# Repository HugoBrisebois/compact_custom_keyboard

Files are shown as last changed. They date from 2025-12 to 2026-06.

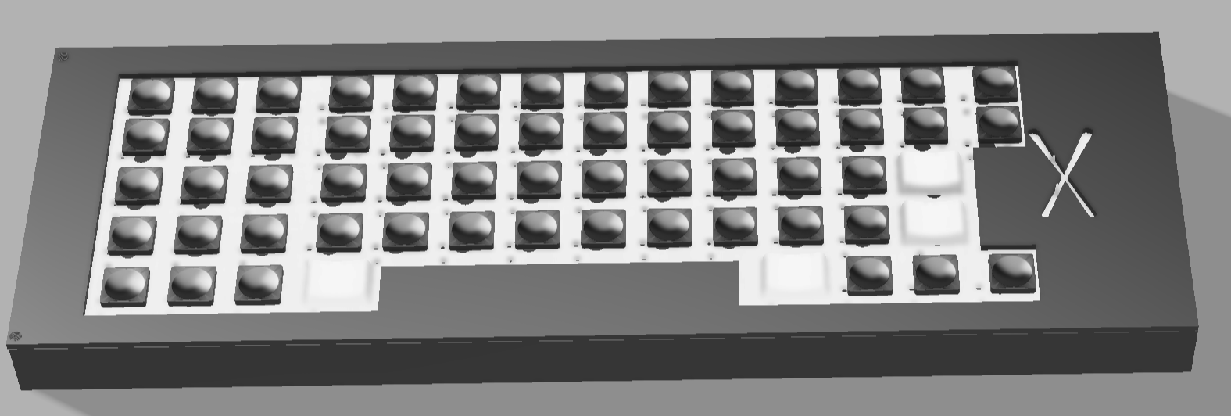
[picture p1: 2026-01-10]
images/render.png

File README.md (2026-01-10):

## Compact Custom Keyboard

This is a compact Keyboard the is powered by a raspberry pi pico and is a hotswapable kailth choc mini keyswitches, the keyboard also has LEDs that can be used for a aestetic lighting and as light to see what you are typing.
The Keyboard is also a 60% keyboard meaning that it is quite small while not having too many layers like a 40% one.

# Features
- powered by a raspberry pi pico
- RGB LEDs
- kailth choc mini keyswitches
- 3d Printed keyswitches

# Reason for build this project
i wanted a keyboard that is completely custom to me and is also something that i can use in a cyberdeck project that i want to build later on. this keyboard is also perfect for everyday use and i am looking forward to using this keyboard too.
case
PCB
3D-render-PCB
Schematic


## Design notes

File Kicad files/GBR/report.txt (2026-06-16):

Plotted to 'C:\Users\iCan Student\OneDrive\Bureau\projects\kicad\compact_custom_keyboard\GBR\keyboardepi pico-F_Cu.gbr'.
Plotted to 'C:\Users\iCan Student\OneDrive\Bureau\projects\kicad\compact_custom_keyboard\GBR\keyboardepi pico-B_Cu.gbr'.
Plotted to 'C:\Users\iCan Student\OneDrive\Bureau\projects\kicad\compact_custom_keyboard\GBR\keyboardepi pico-F_Paste.gbr'.
Plotted to 'C:\Users\iCan Student\OneDrive\Bureau\projects\kicad\compact_custom_keyboard\GBR\keyboardepi pico-B_Paste.gbr'.
Plotted to 'C:\Users\iCan Student\OneDrive\Bureau\projects\kicad\compact_custom_keyboard\GBR\keyboardepi pico-F_Silkscreen.gbr'.
Plotted to 'C:\Users\iCan Student\OneDrive\Bureau\projects\kicad\compact_custom_keyboard\GBR\keyboardepi pico-B_Silkscreen.gbr'.
Plotted to 'C:\Users\iCan Student\OneDrive\Bureau\projects\kicad\compact_custom_keyboard\GBR\keyboardepi pico-F_Mask.gbr'.
Plotted to 'C:\Users\iCan Student\OneDrive\Bureau\projects\kicad\compact_custom_keyboard\GBR\keyboardepi pico-B_Mask.gbr'.
Plotted to 'C:\Users\iCan Student\OneDrive\Bureau\projects\kicad\compact_custom_keyboard\GBR\keyboardepi pico-Edge_Cuts.gbr'.
Created Gerber job file 'C:\Users\iCan Student\OneDrive\Bureau\projects\kicad\compact_custom_keyboard\GBR\keyboardepi pico-job.gbrjob'.
Info: Done.
Info: Done.

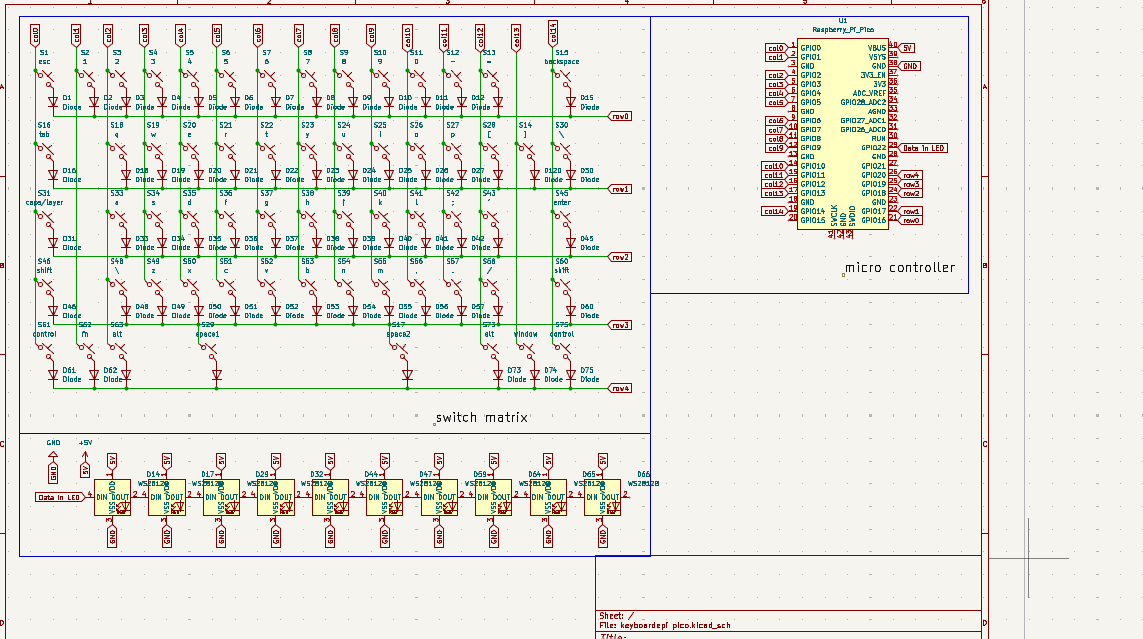
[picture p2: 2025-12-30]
images/Schematic.png

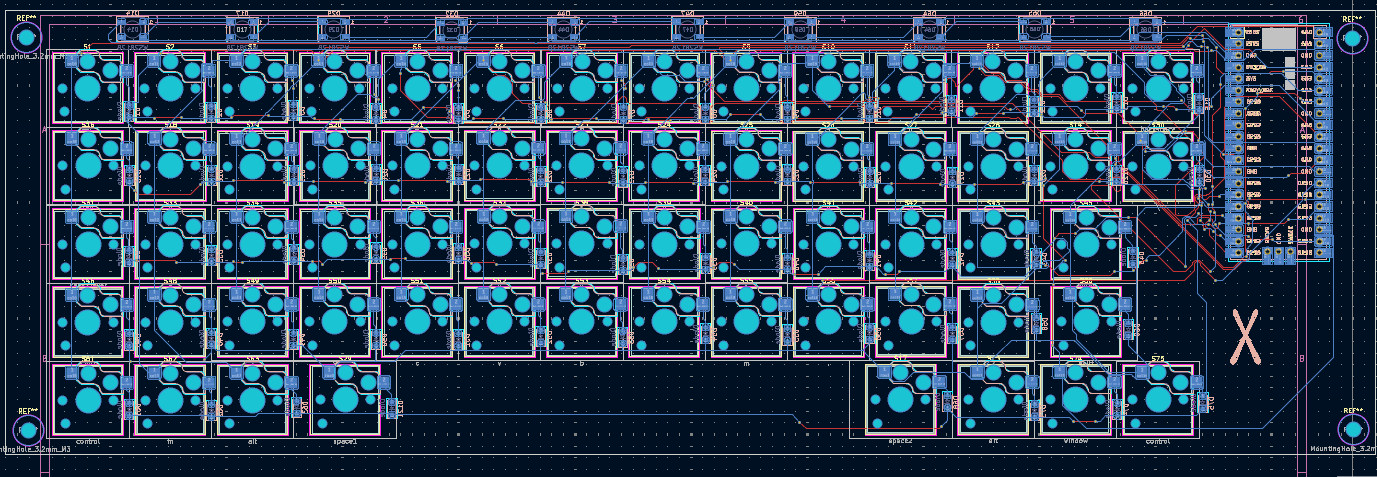
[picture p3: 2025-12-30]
images/PCB.png

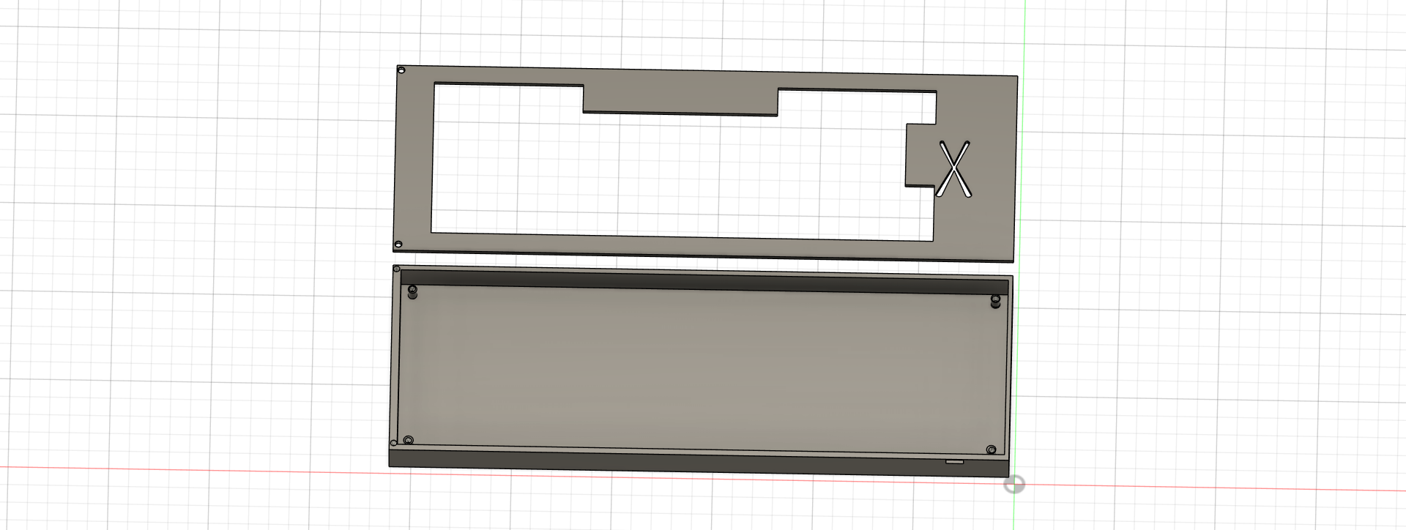
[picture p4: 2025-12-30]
images/case.png

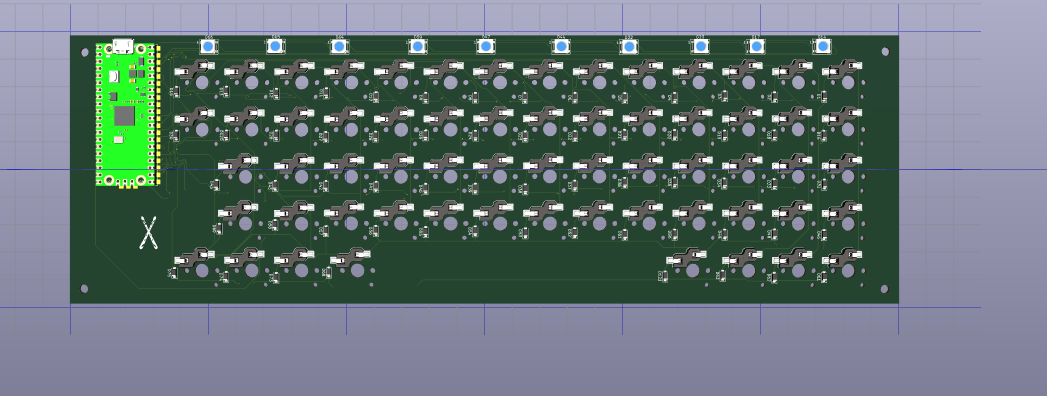
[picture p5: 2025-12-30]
images/3D-render-PCB.png

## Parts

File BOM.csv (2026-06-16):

Reference | Qty | Value | DNP | Exclude from BOM | Exclude from Board | Footprint | Datasheet | Price | Website
D1,D2,D3,D4,D5,D6,D7,D8,D9,D10,D11,D12,D13,D15,D16,D18,D19,D20,D21,D22,D23,D24,D25,D26,D27,D28,D30,D31,D33,D34,D35,D36,D37,D38,D39,D40,D41,D42,D43,D45,D46,D48,D49,D50,D51,D52,D53,D54,D55,D56,D57,D58,D60,D61,D62,D63,D68,D73,D74,D75,D120,D121 | 62 | Diode |  |  |  | Diode_SMD:D_SOD-123F |  | $1.41 | https://www.aliexpress.com/item/1005007536859190.html?curPageLogUid=P8NopE6CzZ6E
D14,D17,D29,D32,D44,D47,D59,D64,D65,D66 | 10 | WS2812B |  |  |  | LED_SMD:LED_WS2812B_PLCC4_5.0x5.0mm_P3.2mm | https://cdn-shop.adafruit.com/datasheets/WS2812B.pdf | $1.74 | https://www.aliexpress.com/item/1005001376489095.html?curPageLogUid=NBeugOt4vb7Q
S1 | 1 | esc |  |  |  | PCM_Switch_Keyboard_Hotswap_Kailh:SW_Hotswap_Kailh_Choc_V1V2_1.00u | ~ |  | 0.35 | unit price
S2 | 1 | 1 |  |  |  | PCM_Switch_Keyboard_Hotswap_Kailh:SW_Hotswap_Kailh_Choc_V1V2_1.00u | ~ |  | 0.35 | unit price
S3 | 1 | 2 |  |  |  | PCM_Switch_Keyboard_Hotswap_Kailh:SW_Hotswap_Kailh_Choc_V1V2_1.00u | ~ |  | 0.35 | unit price
S4 | 1 | 3 |  |  |  | PCM_Switch_Keyboard_Hotswap_Kailh:SW_Hotswap_Kailh_Choc_V1V2_1.00u | ~ |  | 0.35 | unit price
S5 | 1 | 4 |  |  |  | PCM_Switch_Keyboard_Hotswap_Kailh:SW_Hotswap_Kailh_Choc_V1V2_1.00u | ~ |  | 0.35 | unit price
S6 | 1 | 5 |  |  |  | PCM_Switch_Keyboard_Hotswap_Kailh:SW_Hotswap_Kailh_Choc_V1V2_1.00u | ~ |  | 0.35 | unit price
S7 | 1 | 6 |  |  |  | PCM_Switch_Keyboard_Hotswap_Kailh:SW_Hotswap_Kailh_Choc_V1V2_1.00u | ~ |  | 0.35 | unit price
S8 | 1 | 7 |  |  |  | PCM_Switch_Keyboard_Hotswap_Kailh:SW_Hotswap_Kailh_Choc_V1V2_1.00u | ~ |  | 0.35 | unit price
S9 | 1 | 8 |  |  |  | PCM_Switch_Keyboard_Hotswap_Kailh:SW_Hotswap_Kailh_Choc_V1V2_1.00u | ~ |  | 0.35 | unit price
S10 | 1 | 9 |  |  |  | PCM_Switch_Keyboard_Hotswap_Kailh:SW_Hotswap_Kailh_Choc_V1V2_1.00u | ~ |  | 0.35 | unit price
S11 | 1 | 0 |  |  |  | PCM_Switch_Keyboard_Hotswap_Kailh:SW_Hotswap_Kailh_Choc_V1V2_1.00u | ~ |  | 0.35 | unit price
S12 | 1 | - |  |  |  | PCM_Switch_Keyboard_Hotswap_Kailh:SW_Hotswap_Kailh_Choc_V1V2_1.00u | ~ |  | 0.35 | unit price
S13 | 1 | = |  |  |  | PCM_Switch_Keyboard_Hotswap_Kailh:SW_Hotswap_Kailh_Choc_V1V2_1.00u | ~ |  | 0.35 | unit price
S14 | 1 | ] |  |  |  | PCM_Switch_Keyboard_Hotswap_Kailh:SW_Hotswap_Kailh_Choc_V1V2_1.00u | ~ |  | 0.35 | unit price
S15 | 1 | backspace |  |  |  | PCM_Switch_Keyboard_Hotswap_Kailh:SW_Hotswap_Kailh_Choc_V1V2_1.00u | ~ |  | 0.35 | unit price
S16 | 1 | tab |  |  |  | PCM_Switch_Keyboard_Hotswap_Kailh:SW_Hotswap_Kailh_Choc_V1V2_1.00u | ~ |  | 0.35 | unit price
S17 | 1 | space2 |  |  |  | PCM_Switch_Keyboard_Hotswap_Kailh:SW_Hotswap_Kailh_Choc_V1V2_1.25u | ~ |  | 0.35 | unit price
S18 | 1 | q |  |  |  | PCM_Switch_Keyboard_Hotswap_Kailh:SW_Hotswap_Kailh_Choc_V1V2_1.00u | ~ |  | 0.35 | unit price
S19 | 1 | w |  |  |  | PCM_Switch_Keyboard_Hotswap_Kailh:SW_Hotswap_Kailh_Choc_V1V2_1.00u | ~ |  | 0.35 | unit price
S20 | 1 | e |  |  |  | PCM_Switch_Keyboard_Hotswap_Kailh:SW_Hotswap_Kailh_Choc_V1V2_1.00u | ~ |  | 0.35 | unit price
S21 | 1 | r |  |  |  | PCM_Switch_Keyboard_Hotswap_Kailh:SW_Hotswap_Kailh_Choc_V1V2_1.00u | ~ |  | 0.35 | unit price
S22 | 1 | t |  |  |  | PCM_Switch_Keyboard_Hotswap_Kailh:SW_Hotswap_Kailh_Choc_V1V2_1.00u | ~ |  | 0.35 | unit price
S23 | 1 | y |  |  |  | PCM_Switch_Keyboard_Hotswap_Kailh:SW_Hotswap_Kailh_Choc_V1V2_1.00u | ~ |  | 0.35 | unit price
S24 | 1 | u |  |  |  | PCM_Switch_Keyboard_Hotswap_Kailh:SW_Hotswap_Kailh_Choc_V1V2_1.00u | ~ |  | 0.35 | unit price
S25 | 1 | i |  |  |  | PCM_Switch_Keyboard_Hotswap_Kailh:SW_Hotswap_Kailh_Choc_V1V2_1.00u | ~ |  | 0.35 | unit price
S26 | 1 | o |  |  |  | PCM_Switch_Keyboard_Hotswap_Kailh:SW_Hotswap_Kailh_Choc_V1V2_1.00u | ~ |  | 0.35 | unit price
S27 | 1 | p |  |  |  | PCM_Switch_Keyboard_Hotswap_Kailh:SW_Hotswap_Kailh_Choc_V1V2_1.00u | ~ |  | 0.35 | unit price
S28 | 1 | [ |  |  |  | PCM_Switch_Keyboard_Hotswap_Kailh:SW_Hotswap_Kailh_Choc_V1V2_1.00u | ~ |  | 0.35 | unit price
S29 | 1 | space1 |  |  |  | PCM_Switch_Keyboard_Hotswap_Kailh:SW_Hotswap_Kailh_Choc_V1V2_1.25u | ~ |  | 0.35 | unit price
S30,S48 | 2 | \ |  |  |  | PCM_Switch_Keyboard_Hotswap_Kailh:SW_Hotswap_Kailh_Choc_V1V2_1.00u | ~ |  | 0.35 | unit price
S31 | 1 | caps/layer |  |  |  | PCM_Switch_Keyboard_Hotswap_Kailh:SW_Hotswap_Kailh_Choc_V1V2_1.00u | ~ |  | 0.35 | unit price
S33 | 1 | a |  |  |  | PCM_Switch_Keyboard_Hotswap_Kailh:SW_Hotswap_Kailh_Choc_V1V2_1.00u | ~ |  | 0.35 | unit price
S34 | 1 | s |  |  |  | PCM_Switch_Keyboard_Hotswap_Kailh:SW_Hotswap_Kailh_Choc_V1V2_1.00u | ~ |  | 0.35 | unit price
S35 | 1 | d |  |  |  | PCM_Switch_Keyboard_Hotswap_Kailh:SW_Hotswap_Kailh_Choc_V1V2_1.00u | ~ |  | 0.35 | unit price
S36 | 1 | f |  |  |  | PCM_Switch_Keyboard_Hotswap_Kailh:SW_Hotswap_Kailh_Choc_V1V2_1.00u | ~ |  | 0.35 | unit price
S37 | 1 | g |  |  |  | PCM_Switch_Keyboard_Hotswap_Kailh:SW_Hotswap_Kailh_Choc_V1V2_1.00u | ~ |  | 0.35 | unit price
S38 | 1 | h |  |  |  | PCM_Switch_Keyboard_Hotswap_Kailh:SW_Hotswap_Kailh_Choc_V1V2_1.00u | ~ |  | 0.35 | unit price
S39 | 1 | j |  |  |  | PCM_Switch_Keyboard_Hotswap_Kailh:SW_Hotswap_Kailh_Choc_V1V2_1.00u | ~ |  | 0.35 | unit price
S40 | 1 | k |  |  |  | PCM_Switch_Keyboard_Hotswap_Kailh:SW_Hotswap_Kailh_Choc_V1V2_1.00u | ~ |  | 0.35 | unit price
S41 | 1 | l |  |  |  | PCM_Switch_Keyboard_Hotswap_Kailh:SW_Hotswap_Kailh_Choc_V1V2_1.00u | ~ |  | 0.35 | unit price
S42 | 1 | ; |  |  |  | PCM_Switch_Keyboard_Hotswap_Kailh:SW_Hotswap_Kailh_Choc_V1V2_1.00u | ~ |  | 0.35 | unit price
S43 | 1 | ' |  |  |  | PCM_Switch_Keyboard_Hotswap_Kailh:SW_Hotswap_Kailh_Choc_V1V2_1.00u | ~ |  | 0.35 | unit price
S45 | 1 | enter |  |  |  | PCM_Switch_Keyboard_Hotswap_Kailh:SW_Hotswap_Kailh_Choc_V1V2_1.25u | ~ |  | 0.35 | unit price
S46 | 1 | shift |  |  |  | PCM_Switch_Keyboard_Hotswap_Kailh:SW_Hotswap_Kailh_Choc_V1V2_1.00u | ~ |  | 0.35 | unit price
S49 | 1 | z |  |  |  | PCM_Switch_Keyboard_Hotswap_Kailh:SW_Hotswap_Kailh_Choc_V1V2_1.00u | ~ |  | 0.35 | unit price
S50 | 1 | x |  |  |  | PCM_Switch_Keyboard_Hotswap_Kailh:SW_Hotswap_Kailh_Choc_V1V2_1.00u | ~ |  | 0.35 | unit price
S51 | 1 | c |  |  |  | PCM_Switch_Keyboard_Hotswap_Kailh:SW_Hotswap_Kailh_Choc_V1V2_1.00u | ~ |  | 0.35 | unit price
S52 | 1 | v |  |  |  | PCM_Switch_Keyboard_Hotswap_Kailh:SW_Hotswap_Kailh_Choc_V1V2_1.00u | ~ |  | 0.35 | unit price
S53 | 1 | b |  |  |  | PCM_Switch_Keyboard_Hotswap_Kailh:SW_Hotswap_Kailh_Choc_V1V2_1.00u | ~ |  | 0.35 | unit price
S54 | 1 | n |  |  |  | PCM_Switch_Keyboard_Hotswap_Kailh:SW_Hotswap_Kailh_Choc_V1V2_1.00u | ~ |  | 0.35 | unit price
S55 | 1 | m |  |  |  | PCM_Switch_Keyboard_Hotswap_Kailh:SW_Hotswap_Kailh_Choc_V1V2_1.00u | ~ |  | 0.35 | unit price
S56 | 1 | , |  |  |  | PCM_Switch_Keyboard_Hotswap_Kailh:SW_Hotswap_Kailh_Choc_V1V2_1.00u | ~ |  | 0.35 | unit price
S57 | 1 | . |  |  |  | PCM_Switch_Keyboard_Hotswap_Kailh:SW_Hotswap_Kailh_Choc_V1V2_1.00u | ~ |  | 0.35 | unit price
S58 | 1 | / |  |  |  | PCM_Switch_Keyboard_Hotswap_Kailh:SW_Hotswap_Kailh_Choc_V1V2_1.00u | ~ |  | 0.35 | unit price
S60 | 1 | shift |  |  |  | PCM_Switch_Keyboard_Hotswap_Kailh:SW_Hotswap_Kailh_Choc_V1V2_1.25u | ~ |  | 0.35 | unit price
S61,S75 | 2 | control |  |  |  | PCM_Switch_Keyboard_Hotswap_Kailh:SW_Hotswap_Kailh_Choc_V1V2_1.00u | ~ |  | 0.35 | unit price
S62 | 1 | fn |  |  |  | PCM_Switch_Keyboard_Hotswap_Kailh:SW_Hotswap_Kailh_Choc_V1V2_1.00u | ~ |  | 0.35 | unit price
S63,S73 | 2 | alt |  |  |  | PCM_Switch_Keyboard_Hotswap_Kailh:SW_Hotswap_Kailh_Choc_V1V2_1.00u | ~ |  | 0.35 | unit price
S74 | 1 | window |  |  |  | PCM_Switch_Keyboard_Hotswap_Kailh:SW_Hotswap_Kailh_Choc_V1V2_1.00u | ~ |  | 0.35 | unit price
U1 | 1 | Raspberry_Pi_Pico |  |  |  | ScottoKeebs_MCU:Raspberry_Pi_Pico |  | $3.80 | https://www.aliexpress.com/item/1005008379427391.html?mp=1
PCB Total Cost + shipping |  |  |  |  |  |  |  | $30.25 | shipping option | DDP
Total Keyswitches |  |  | 62 |  |  |  |  | $27.52 | https://www.aliexpress.us/item/3256808620484354.html?curPageLogUid=S7K5j9DP5AhE
 |  |  |  |  |  |  |  | (First Purchase discount)
Total Hotswap sockets |  |  | 62 |  |  |  |  | $8.32 | https://www.aliexpress.com/item/1005009312876316.html?curPageLogUid=QmGdVVpTZLfK
 |  |  |  |  | Total Cost |  |  | $73.04

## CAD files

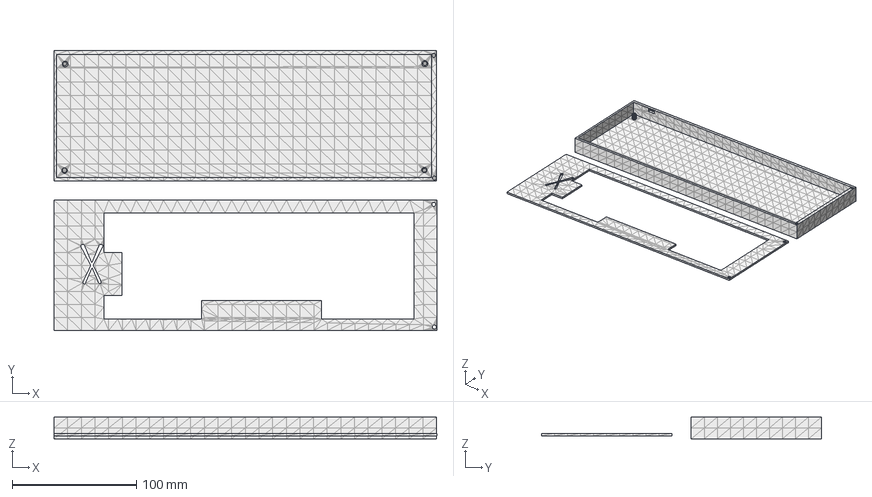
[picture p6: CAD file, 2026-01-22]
3D model case/Case.step
308.3 x 225.3 x 17.5 mm

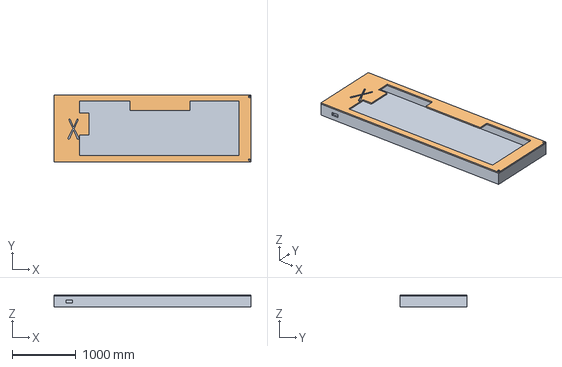
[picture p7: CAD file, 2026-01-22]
3D model case/PCB with Case(keyboard).step
3083.4 x 1050.2 x 195.0 mm

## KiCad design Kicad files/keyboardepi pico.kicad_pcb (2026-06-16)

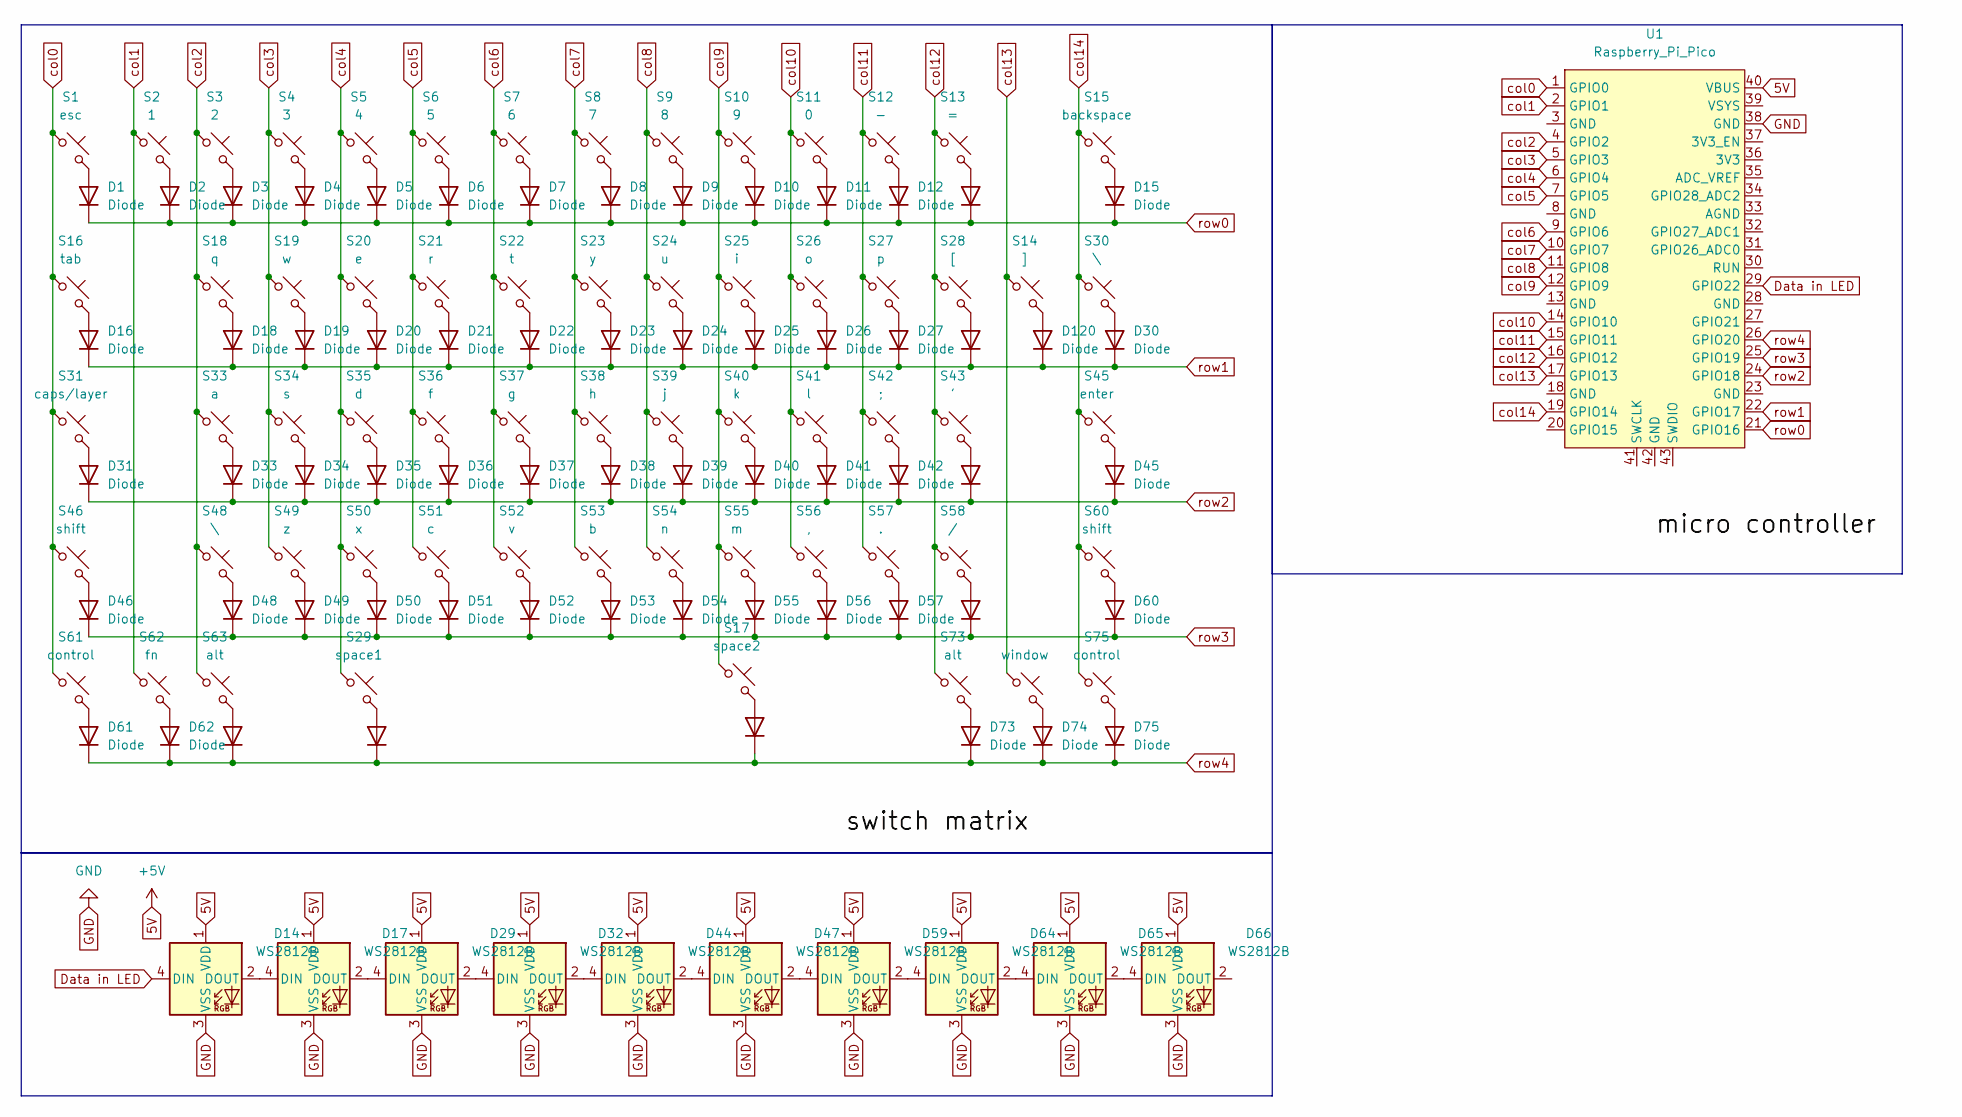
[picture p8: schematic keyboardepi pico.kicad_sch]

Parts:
D1, D2, D3, D4, D5, D6, D7, D8, D9, D10, D11, D12, D13, D15, D16, D18, D19, D20, D21, D22, D23, D24, D25, D26, D27, D28, D30, D31, D33, D34, D35, D36, D37, D38, D39, D40, D41, D42, D43, D45, D46, D48, D49, D50, D51, D52, D53, D54, D55, D56, D57, D58, D60, D61, D62, D63, D68, D73, D74, D75, D120, D121: Diode; Diode_DO-35
D14, D17, D29, D32, D44, D47, D59, D64, D65, D66: WS2812B; LED_WS2812B_PLCC4_5.0x5.0mm_P3.2mm
S1: esc; SW_Hotswap_Kailh_Choc_V1V2_1.00u
S2: 1; SW_Hotswap_Kailh_Choc_V1V2_1.00u
S3: 2; SW_Hotswap_Kailh_Choc_V1V2_1.00u
S4: 3; SW_Hotswap_Kailh_Choc_V1V2_1.00u
S5: 4; SW_Hotswap_Kailh_Choc_V1V2_1.00u
S6: 5; SW_Hotswap_Kailh_Choc_V1V2_1.00u
S7: 6; SW_Hotswap_Kailh_Choc_V1V2_1.00u
S8: 7; SW_Hotswap_Kailh_Choc_V1V2_1.00u
S9: 8; SW_Hotswap_Kailh_Choc_V1V2_1.00u
S10: 9; SW_Hotswap_Kailh_Choc_V1V2_1.00u
S11: 0; SW_Hotswap_Kailh_Choc_V1V2_1.00u
S12: -; SW_Hotswap_Kailh_Choc_V1V2_1.00u
S13: =; SW_Hotswap_Kailh_Choc_V1V2_1.00u
S14: ]; SW_Hotswap_Kailh_Choc_V1V2_1.00u
S15: backspace; SW_Hotswap_Kailh_Choc_V1V2_1.00u
S16: tab; SW_Hotswap_Kailh_Choc_V1V2_1.00u
S17: space2; SW_Hotswap_Kailh_Choc_V1V2_1.25u
S18: q; SW_Hotswap_Kailh_Choc_V1V2_1.00u
S19: w; SW_Hotswap_Kailh_Choc_V1V2_1.00u
S20: e; SW_Hotswap_Kailh_Choc_V1V2_1.00u
S21: r; SW_Hotswap_Kailh_Choc_V1V2_1.00u
S22: t; SW_Hotswap_Kailh_Choc_V1V2_1.00u
S23: y; SW_Hotswap_Kailh_Choc_V1V2_1.00u
S24: u; SW_Hotswap_Kailh_Choc_V1V2_1.00u
S25: i; SW_Hotswap_Kailh_Choc_V1V2_1.00u
S26: o; SW_Hotswap_Kailh_Choc_V1V2_1.00u
S27: p; SW_Hotswap_Kailh_Choc_V1V2_1.00u
S28: [; SW_Hotswap_Kailh_Choc_V1V2_1.00u
S29: space1; SW_Hotswap_Kailh_Choc_V1V2_1.25u
S30, S48: \; SW_Hotswap_Kailh_Choc_V1V2_1.00u
S31: caps/layer; SW_Hotswap_Kailh_Choc_V1V2_1.00u
S33: a; SW_Hotswap_Kailh_Choc_V1V2_1.00u
S34: s; SW_Hotswap_Kailh_Choc_V1V2_1.00u
S35: d; SW_Hotswap_Kailh_Choc_V1V2_1.00u
S36: f; SW_Hotswap_Kailh_Choc_V1V2_1.00u
S37: g; SW_Hotswap_Kailh_Choc_V1V2_1.00u
S38: h; SW_Hotswap_Kailh_Choc_V1V2_1.00u
S39: j; SW_Hotswap_Kailh_Choc_V1V2_1.00u
S40: k; SW_Hotswap_Kailh_Choc_V1V2_1.00u
S41: l; SW_Hotswap_Kailh_Choc_V1V2_1.00u
S42: ;; SW_Hotswap_Kailh_Choc_V1V2_1.00u
S43: '; SW_Hotswap_Kailh_Choc_V1V2_1.00u
S45: enter; SW_Hotswap_Kailh_Choc_V1V2_1.25u
S46: shift; SW_Hotswap_Kailh_Choc_V1V2_1.00u
S49: z; SW_Hotswap_Kailh_Choc_V1V2_1.00u
S50: x; SW_Hotswap_Kailh_Choc_V1V2_1.00u
S51: c; SW_Hotswap_Kailh_Choc_V1V2_1.00u
S52: v; SW_Hotswap_Kailh_Choc_V1V2_1.00u
S53: b; SW_Hotswap_Kailh_Choc_V1V2_1.00u
S54: n; SW_Hotswap_Kailh_Choc_V1V2_1.00u
S55: m; SW_Hotswap_Kailh_Choc_V1V2_1.00u
S56: ,; SW_Hotswap_Kailh_Choc_V1V2_1.00u
S57: .; SW_Hotswap_Kailh_Choc_V1V2_1.00u
S58: /; SW_Hotswap_Kailh_Choc_V1V2_1.00u
S60: shift; SW_Hotswap_Kailh_Choc_V1V2_1.25u
S61, S75: control; SW_Hotswap_Kailh_Choc_V1V2_1.00u
S62: fn; SW_Hotswap_Kailh_Choc_V1V2_1.00u
S63, S73: alt; SW_Hotswap_Kailh_Choc_V1V2_1.00u
S74: window; SW_Hotswap_Kailh_Choc_V1V2_1.00u
U1: Raspberry_Pi_Pico

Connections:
5V: D14.1 (VDD), D17.1 (VDD), D29.1 (VDD), D32.1 (VDD), D44.1 (VDD), D47.1 (VDD), D59.1 (VDD), D64.1 (VDD), D65.1 (VDD), D66.1 (VDD), U1.40 (VBUS)
Data in LED: D14.4 (DIN), U1.29 (GPIO22)
GND: D14.3 (VSS), D17.3 (VSS), D29.3 (VSS), D32.3 (VSS), D44.3 (VSS), D47.3 (VSS), D59.3 (VSS), D64.3 (VSS), D65.3 (VSS), D66.3 (VSS), U1.38 (GND)
unnamed: D1.2 (A), S1.2
unnamed: D2.2 (A), S2.2
unnamed: D3.2 (A), S3.2
unnamed: D4.2 (A), S4.2
unnamed: D5.2 (A), S5.2
unnamed: D6.2 (A), S6.2
unnamed: D7.2 (A), S7.2
unnamed: D8.2 (A), S8.2
unnamed: D9.2 (A), S9.2
unnamed: D10.2 (A), S10.2
unnamed: D11.2 (A), S11.2
unnamed: D12.2 (A), S12.2
unnamed: D13.2 (A), S13.2
unnamed: D14.2 (DOUT), D17.4 (DIN)
unnamed: D15.2 (A), S15.2
unnamed: D16.2 (A), S16.2
unnamed: D17.2 (DOUT), D29.4 (DIN)
unnamed: D18.2 (A), S18.2
unnamed: D19.2 (A), S19.2
unnamed: D20.2 (A), S20.2
unnamed: D21.2 (A), S21.2
unnamed: D22.2 (A), S22.2
unnamed: D23.2 (A), S23.2
unnamed: D24.2 (A), S24.2
unnamed: D25.2 (A), S25.2
unnamed: D26.2 (A), S26.2
unnamed: D27.2 (A), S27.2
unnamed: D28.2 (A), S28.2
unnamed: D29.2 (DOUT), D32.4 (DIN)
unnamed: D30.2 (A), S30.2
unnamed: D31.2 (A), S31.2
unnamed: D32.2 (DOUT), D44.4 (DIN)
unnamed: D33.2 (A), S33.2
unnamed: D34.2 (A), S34.2
unnamed: D35.2 (A), S35.2
unnamed: D36.2 (A), S36.2
unnamed: D37.2 (A), S37.2
unnamed: D38.2 (A), S38.2
unnamed: D39.2 (A), S39.2
unnamed: D40.2 (A), S40.2
unnamed: D41.2 (A), S41.2
unnamed: D42.2 (A), S42.2
unnamed: D43.2 (A), S43.2
unnamed: D44.2 (DOUT), D47.4 (DIN)
unnamed: D45.2 (A), S45.2
unnamed: D46.2 (A), S46.2
unnamed: D47.2 (DOUT), D59.4 (DIN)
unnamed: D48.2 (A), S48.2
unnamed: D49.2 (A), S49.2
unnamed: D50.2 (A), S50.2
unnamed: D51.2 (A), S51.2
unnamed: D52.2 (A), S52.2
unnamed: D53.2 (A), S53.2
unnamed: D54.2 (A), S54.2
unnamed: D55.2 (A), S55.2
unnamed: D56.2 (A), S56.2
unnamed: D57.2 (A), S57.2
unnamed: D58.2 (A), S58.2
unnamed: D59.2 (DOUT), D64.4 (DIN)
unnamed: D60.2 (A), S60.2
unnamed: D61.2 (A), S61.2
unnamed: D62.2 (A), S62.2
unnamed: D63.2 (A), S63.2
unnamed: D64.2 (DOUT), D65.4 (DIN)
unnamed: D65.2 (DOUT), D66.4 (DIN)
unnamed: D68.2 (A), S17.2
unnamed: D73.2 (A), S73.2
unnamed: D74.2 (A), S74.2
unnamed: D75.2 (A), S75.2
unnamed: D120.2 (A), S14.2
unnamed: D121.2 (A), S29.2
col0: S1.1, S16.1, S31.1, S46.1, S61.1, U1.1 (GPIO0)
col1: S2.1, S62.1, U1.2 (GPIO1)
col2: S3.1, S18.1, S33.1, S48.1, S63.1, U1.4 (GPIO2)
col3: S4.1, S19.1, S34.1, S49.1, U1.5 (GPIO3)
col4: S5.1, S20.1, S29.1, S35.1, S50.1, U1.6 (GPIO4)
col5: S6.1, S21.1, S36.1, S51.1, U1.7 (GPIO5)
col6: S7.1, S22.1, S37.1, S52.1, U1.9 (GPIO6)
col7: S8.1, S23.1, S38.1, S53.1, U1.10 (GPIO7)
col8: S9.1, S24.1, S39.1, S54.1, U1.11 (GPIO8)
col9: S10.1, S17.1, S25.1, S40.1, S55.1, U1.12 (GPIO9)
col10: S11.1, S26.1, S41.1, S56.1, U1.14 (GPIO10)
col11: S12.1, S27.1, S42.1, S57.1, U1.15 (GPIO11)
col12: S13.1, S28.1, S43.1, S58.1, S73.1, U1.16 (GPIO12)
col13: S14.1, S74.1, U1.17 (GPIO13)
col14: S15.1, S30.1, S45.1, S60.1, S75.1, U1.19 (GPIO14)
row0: D1.1 (K), D2.1 (K), D3.1 (K), D4.1 (K), D5.1 (K), D6.1 (K), D7.1 (K), D8.1 (K), D9.1 (K), D10.1 (K), D11.1 (K), D12.1 (K), D13.1 (K), D15.1 (K), U1.21 (GPIO16)
row1: D16.1 (K), D18.1 (K), D19.1 (K), D20.1 (K), D21.1 (K), D22.1 (K), D23.1 (K), D24.1 (K), D25.1 (K), D26.1 (K), D27.1 (K), D28.1 (K), D30.1 (K), D120.1 (K), U1.22 (GPIO17)
row2: D31.1 (K), D33.1 (K), D34.1 (K), D35.1 (K), D36.1 (K), D37.1 (K), D38.1 (K), D39.1 (K), D40.1 (K), D41.1 (K), D42.1 (K), D43.1 (K), D45.1 (K), U1.24 (GPIO18)
row3: D46.1 (K), D48.1 (K), D49.1 (K), D50.1 (K), D51.1 (K), D52.1 (K), D53.1 (K), D54.1 (K), D55.1 (K), D56.1 (K), D57.1 (K), D58.1 (K), D60.1 (K), U1.25 (GPIO19)
row4: D61.1 (K), D62.1 (K), D63.1 (K), D68.1 (K), D73.1 (K), D74.1 (K), D75.1 (K), D121.1 (K), U1.26 (GPIO20)

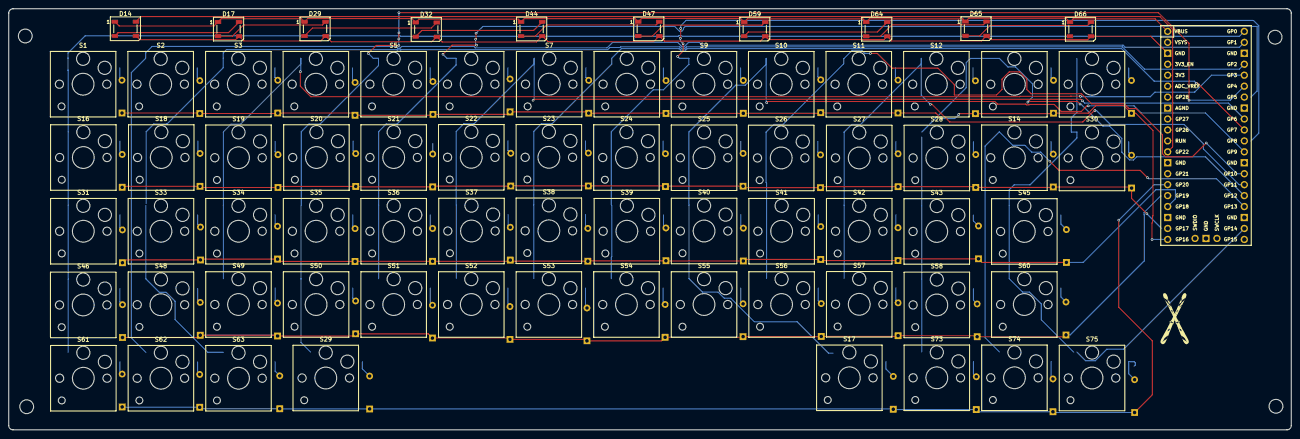
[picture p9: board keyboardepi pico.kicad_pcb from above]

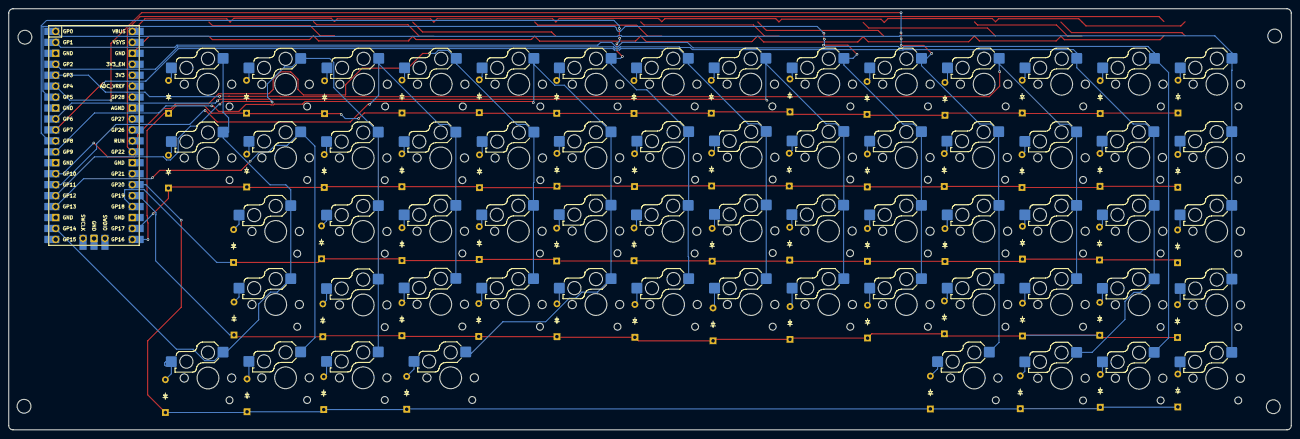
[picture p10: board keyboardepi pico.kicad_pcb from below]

Board: 2 copper layers, 297.5 x 97.7 mm, 135 parts (63 on the bottom side), 94 nets.

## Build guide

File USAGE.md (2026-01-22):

# Compact Keyboard - User Guide

this is your user manual in which you will learn how to make your keyboard a keyboard and learn it's ins and outs.

# what are the specs of this keyboard

this keyboard is powered by a rp2040 raspberrypi Pico with the functionality of being a wired keyboard having a micro usb power connector. the keys on this keyboard are kailth chic mini hotswap meaning that you can always change the keys if you don't like them, as well as have underflow GRB leds from adafruit

# quick start

in order for your keyboard to be a keyboard you will need to flash it so:

- step 1: plug your keyboard into your laptop or desktop and hold the boot button for two seconds. 

- step 2: after holding the boot button of your raspberrypi Pico, it will appear as a disk in which after downloading the .hex file from my repo, you will drag and drop the .hex file or you will copy paste the file in to the raspberrypi Pico disk that has appeared
- step 3: unplug the keyboard and wait 10 seconds. after which, you should be able to plug it back in and start using it, the LEDs should come in, if not I am still working on this problem

# functions of this keyboard 

this keyboard is a 60% layout with 62 keys to accommodate the to spacebars as well as has a second layer to the keyboard to accomidate for the function keys as well as the let you control the underglow.

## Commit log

2025-12-29 Uploaded Schematics and kicad files
    [BOM1.csv, keyboardepi pico.kicad_pcb, keyboardepi pico.kicad_sch]
2025-12-29 organized the directories for the Kicad files
    [keyboardepi pico.kicad_pcb, keyboardepi pico.kicad_sch]
2025-12-29 Updated the PCB
    [keyboardepi pico.kicad_pcb]
2025-12-29 Finished the BOM
    [BOM1.csv]
2025-12-29 finalizing the project for shipping
    [BOM1.csv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]
2025-12-29 adding the case files
2025-12-29 added case file
    added the file with only the case in it
    [case.obj]
2025-12-29 Removed the LEDs
    [keyboardepi pico.kicad_pcb, keyboardepi pico.kicad_sch]
2025-12-29 fixing the PCB
    [keyboardepi pico-B_Cu.gbr, keyboardepi pico-B_Mask.gbr, keyboardepi pico-B_Paste.gbr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]
2025-12-29 fixing files and folders
    [keyboardepi pico-B_Cu.gbr, keyboardepi pico-B_Mask.gbr, keyboardepi pico-B_Paste.gbr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]
2025-12-30 added my logo to the pcb
    [case.obj]
2025-12-30 finishing up to ship the project
    [keyboardepi pico-B_Cu.gbr, keyboardepi pico-B_Mask.gbr, keyboardepi pico-B_Paste.gbr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]
2026-01-21 moving the case.png and removing the journal to re-upload it
    [BOM1.csv]
2026-01-21 made sure that the GBR has drl files as well as has the GBR
    [keyboardepi pico-NPTH.drl, keyboardepi pico-PTH.drl]
2026-01-22 changed the files so that they are .step files
    [Case.step, PCB with Case(keyboard).step, case.obj]
2026-01-27 fixed pricing
    [BOM.csv]
2026-02-12 Modify BOM.csv to include new parts and costs
    Updated BOM.csv to add new components and adjust pricing.
    [BOM.csv]
2026-02-12 Update BOM.csv to add new entries and costs
    [BOM.csv]
2026-06-16 rebuilding gbr files and pcb for better soldering ease
    [keyboardepi pico-B_Cu.gbr, keyboardepi pico-B_Mask.gbr, keyboardepi pico-B_Paste.gbr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]
2026-06-16 rebuilding the gbr files
    [keyboardepi pico-B_Cu.gbr, keyboardepi pico-B_Mask.gbr, keyboardepi pico-B_Paste.gbr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]
